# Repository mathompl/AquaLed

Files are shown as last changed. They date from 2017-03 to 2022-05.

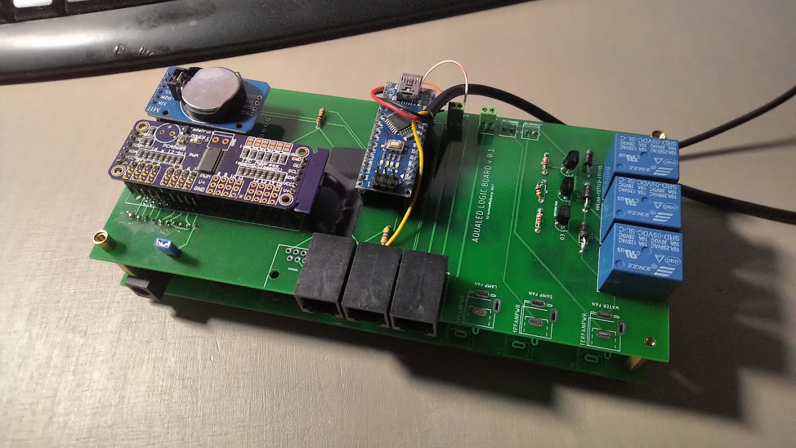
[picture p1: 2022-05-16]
pcb/IMG_20220514_2029458.jpg

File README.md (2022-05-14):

# AquaLed (en)

Arduino PWM LED lamp driver software with LCD support and temperature control for marine, reef or sweetwater aquariums.

Features:
- 8 channel PWM control of LED modules (drivers), with I2C module up to 512 (up to 8 channels on LCD)
- programmable light hours with sunsets and sunrises
- night light support
- 3 digital thermometers with asynchronous temperature read, for: water, lamp and addictional lamp or sump, controlling 3 separate  relays (cooling fans)
- customizable dimming, linear or logarithmic algorith
- bluetooth compatibility with AQma Led Control by Maqu http://magu.pl/aqma-led-control
- full configuration and status using Nextion 2.8" LCD with touch support, including: operational hours, sunset & sunrise hours, thermometers, dimming times, schedule, night mode etc.
- override programs: off, night and user accessible from LCD
- date/time support with RTC module
- screen saver with water temperature and time
- test mode
- moonphases simulation for night light
- all settings stored in EEPROM
- works on Arduino Nano

Example Nextion project attached. I dont have copyright for graphics used, use only as an example.

**Nextion LCD Screenshots**
 
AquaLed
AquaLed
AquaLed
AquaLed
AquaLed
AquaLed
AquaLed
AquaLed
AquaLed
AquaLed

**REQUIREMENTS:**

**Hardware:**
- Arduino Nano or better
- RTC module 
- Bluetooth (optional)
- 3x DS18B20 digital thermometers
- 3x 5v relays modules
- PCA9685 PWM i2c module (optional)
- Nextion 2.8" LCD

**Libraries:**
- Arduino-Temperature-Control-Library (https://github.com/milesburton/Arduino-Temperature-Control-Library) 
- DS1307RTC (https://github.com/PaulStoffregen/DS1307RTC)
- DS18B20 (https://github.com/nettigo/DS18B20)
- OneWire (https://github.com/PaulStoffregen/OneWire)
- Time (https://github.com/PaulStoffregen/Time)
- Adafruit-PWM-Servo-Driver-Library (https://github.com/adafruit/Adafruit-PWM-Servo-Driver-Library)
- or https://github.com/NachtRaveVL/PCA9685-Arduino

**Software:**
- Nextion Editor (https://nextion.itead.cc/download.html)
- Arduino IDE or atom.io

**Configuration:**
Driver configuration is in file aqualed.h

####PINS SETUP:
Configuration on LCD.

####Modules (uncomment to disable). As for now bluetooth and nextion support does not fit into Arduino Nano/UNO etc. flash memory. Use arduino Mega or disable one module support.
```
// modules, uncomment to disable, comment to enable
#define NO_BLUETOOTH
//#define NO_NEXTION
//#define NO_TEMPERATURE
```
####Other
There are many other options for eg. timers resolution, most of them are pretty self-explanatory ;)

**Wiring:**

AquaLed wiring

# AquaLed (pl)

Sterownik lampy LED PWM na Arduino z obsługą termometrów, chłodzenia i wyświetlacza LCD Nextion dla akwariów słodko i słonowodnych.

Możliwości:
- obsługa 8 ściemnialnych kanałów PWM dla modułów LED (driverów), z modułem I2C do 512 kanałów (maksymalnie 8 na wyswietlaczu)
- programowanie godzin świetenia z symulacją wschodów i zachodów słońca
- światło nocne
- obsługa 3 cyfrowych termometrów sterujących pracą 3 przekaźników (np. wentylatorów), np. dla lampy, lampy w sumpie, wody w akwarium
- ściemnianie/rozjaśnianie
- kompatybilność z AQma Led Control by Maqu http://magu.pl/aqma-led-control w zakresie programowania przez Bluetooth
- pełna konfiguracja i status za pomocą wyświetlacza Nextion LCD (przykłady na 2,8"), sterowanie przez dotyk.
- możliwość chwilowego nadpisania działającego programu z wyświetlacza: wyłączenie/wymuszenie światła nocnego/program zdefiniowany
- obsługa godziny i daty
- wygaszacz ekranu z godziną i temperaturą wody
- tryb test
- symulacja faz księżyca
- wszystkie ustawienia zapamiętywane w pamięci EEPROM
- działa z Arduino Nano lub wyższym modelem

Przykładowy program na wyświetlacz załączony.

**Wygląd ekranów na wyświetlaczu **

AquaLed
AquaLed
AquaLed
AquaLed
AquaLed
AquaLed
AquaLed
AquaLed
AquaLed
AquaLed

**Wymagania:**

**Sprzęt:**
- Arduino Nano lub wyższy
- moduł czasu rzeczywistego RTC
- Bluetooth (opcjonalnie)
- 3x termometry cyfrowe DS18B20
- 3x moduły przekaźników 5v
- moduł PCA9685 PWM i2c  (optionalny)
- wyświetlacz Nextion 2.8" LCD lub większy

**Biblioteki:**
- Arduino-Temperature-Control-Library (https://github.com/milesburton/Arduino-Temperature-Control-Library)
- DS1307RTC (https://github.com/PaulStoffregen/DS1307RTC)
- DS18B20 (https://github.com/nettigo/DS18B20)
- OneWire (https://github.com/PaulStoffregen/OneWire)
- Time (https://github.com/PaulStoffregen/Time)
- Adafruit-PWM-Servo-Driver-Library (https://github.com/adafruit/Adafruit-PWM-Servo-Driver-Library)
- lub https://github.com/NachtRaveVL/PCA9685-Arduino

**Oprogramowanie:**
- Nextion Editor (https://nextion.itead.cc/download.html)
- Arduino IDE lub atom.io

**Konfiguracja:**
Konfiguracja w pliku aqualed.h i nextion.h

####Ustawienia pinów PWM:
Konfiguracja z poziomu wyświetlacza.

####Moduły (odkomentuj żeby wyłączyć). Uwaga! Obsługa bluetooth i nextio nie mieści się jednocześnie w pamięcy flash Arduino Nano/Uno itd. wchodzi tylko do Arduino Mega lub podobnego.
```
// modules, uncomment to disable, comment to enable
#define NO_BLUETOOTH
//#define NO_NEXTION
//#define NO_TEMPERATURE
```
####Inne
W pliku konfiguracyjnym można ustawić wiele opcji w tym czasy działania timerów, rozdzielczość załączania przekaźników itd. Większość ustawień wynika z samych nazw stałych :)

**Podłączenie:**

AquaLed wiring

**PCB Prototype boards:**
AquaLed Logic PCB
AquaLed DRIVERS PCB

Support:http://nano-reef.pl/topic/88904-a-qualed-sterownik-led-termometry-lcd-nextion/

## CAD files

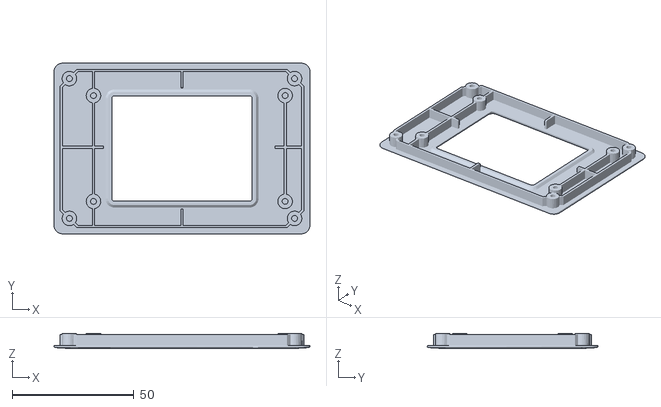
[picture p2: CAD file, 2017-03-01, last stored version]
devs/Aled.,6/Nextion/bezel/nextion_28_bezel.stl
105.0 x 70.0 x 6.15

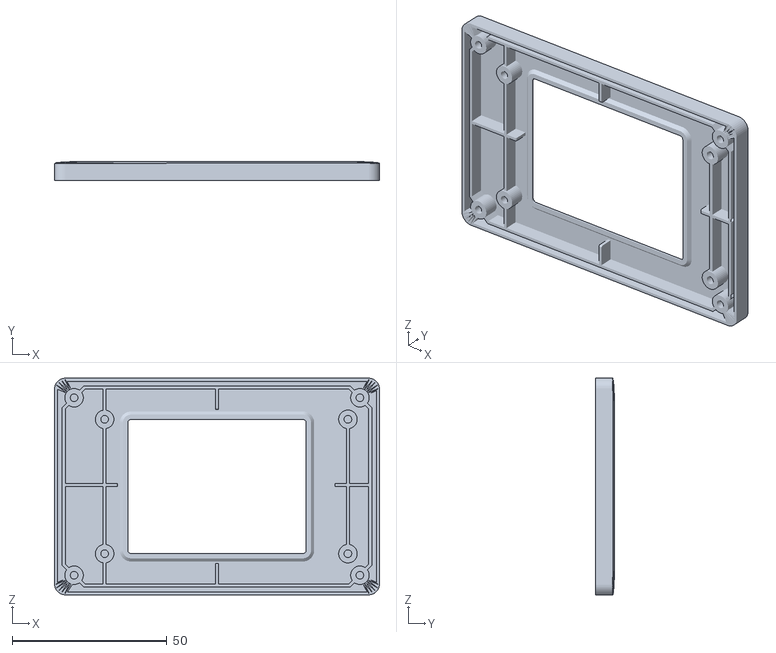
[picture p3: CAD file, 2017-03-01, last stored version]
devs/Aled.,6/Nextion/bezel/nextion-28.stl
105.0 x 6.15 x 70.0

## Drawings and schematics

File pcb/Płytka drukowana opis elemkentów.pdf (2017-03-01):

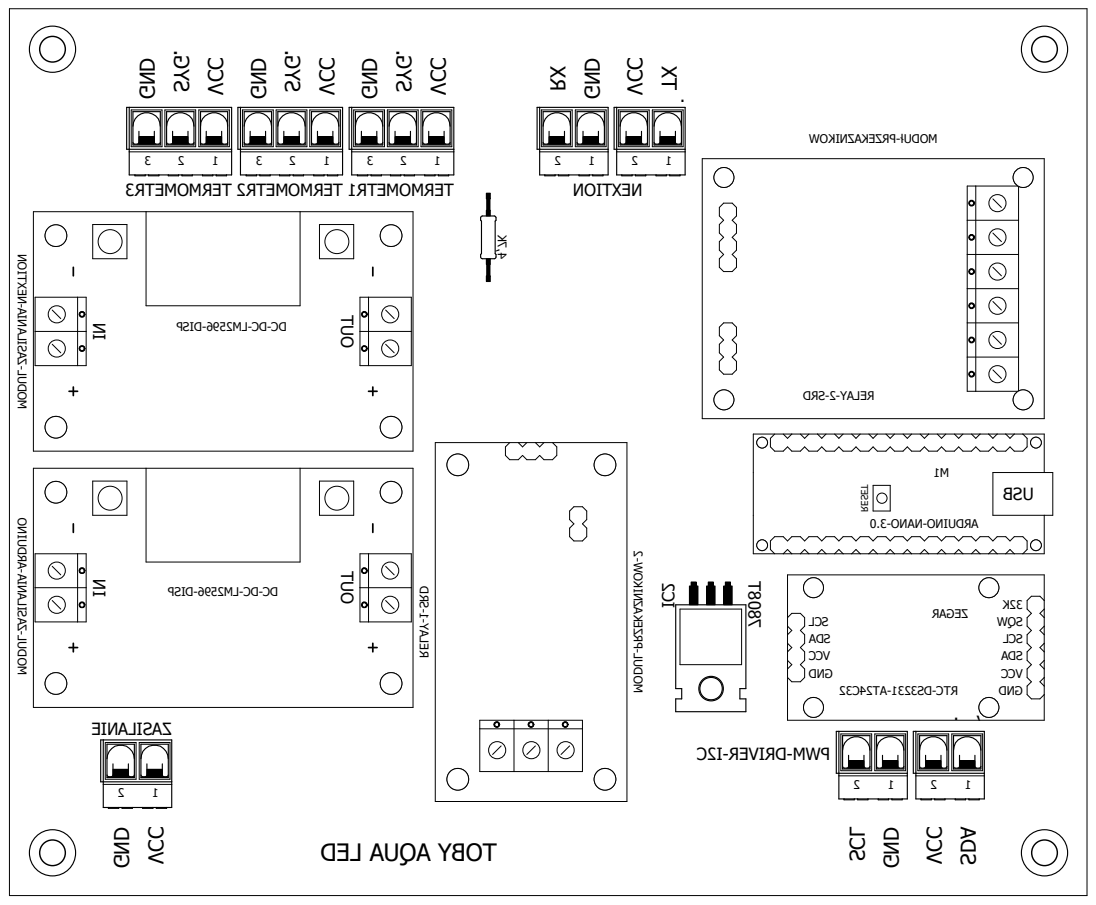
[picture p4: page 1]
MODUł-PRZEKAZNIKOW; TERMOMETR2 TERMOMETR1 TERMOMETR3; . NEXTION; ZASILANIE; PWM-DRIVER-I2C; 32K SQW SCL SDA; VCC GND; SCL SDA

1 2 1 2 1 2 GND VCC SCL GND VCC SDA GND SYG. VCC GND SYG. VCC GND SYG. VCC RX GND VCC TX

M1 MODUL-ZASILANIA-ARDUINO MODUL-ZASILANIA-NEXTION

USB RESET IN OUT IN OUT

DC-DC-LM2596-DISP RELAY-2-SRD

ARDUINO-NANO-3.0 DC-DC-LM2596-DISP

ZEGAR MODUL-PRZEKAZNIKOW-2

RTC-DS3231-AT24C32 RELAY-1-SRD

TOBY AQUA LED

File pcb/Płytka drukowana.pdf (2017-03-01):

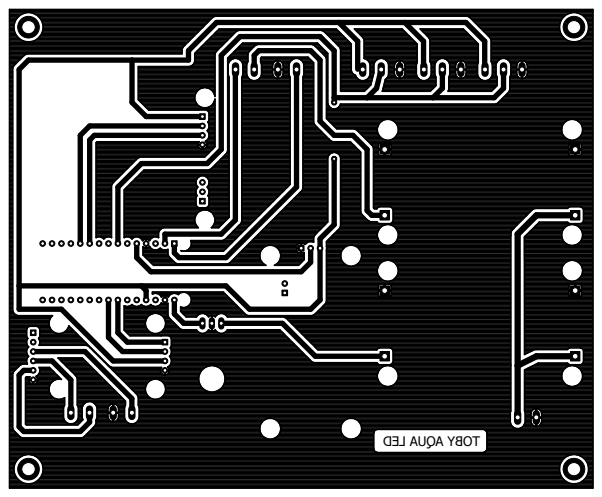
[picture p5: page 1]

TOBY AQUA LED

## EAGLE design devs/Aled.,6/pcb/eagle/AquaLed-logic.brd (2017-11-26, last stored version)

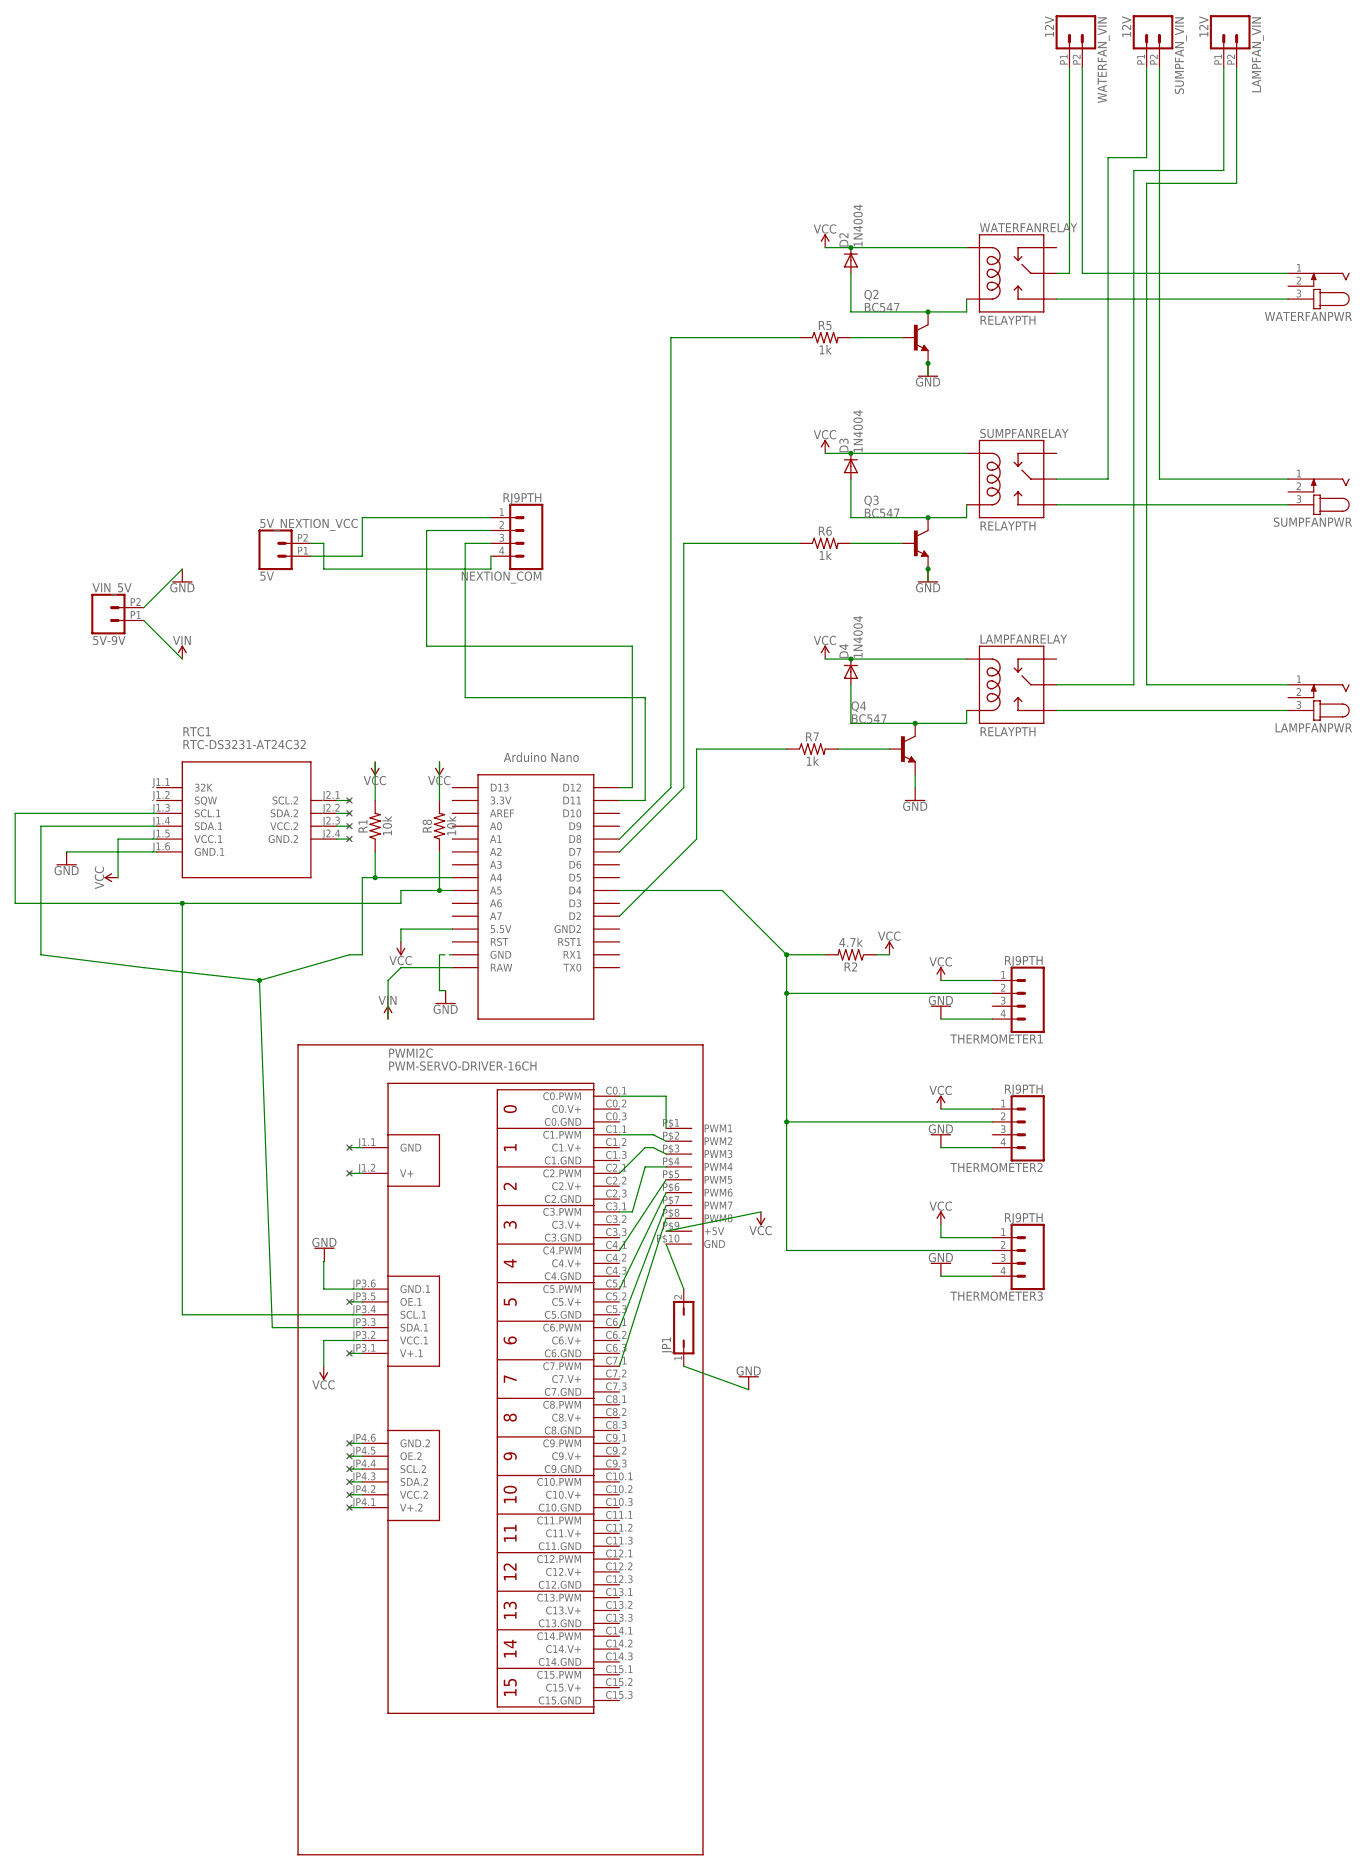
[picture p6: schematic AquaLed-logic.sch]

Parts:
5V_NEXTION_VCC: 5V; 1X02_2.54_SCREWTERM
D2, D3, D4: 1N4004; DO41-10
JP1: JP1Q; JP1
LAMPFANPWR: JACK-PLUG1; SPC4078
LAMPFANRELAY: RELAYPTH; SRD-05VDC-SL-C
LAMPFAN_VIN: 12V; 1X02_2.54_SCREWTERM
NEXTION_COM: RJ9PTH; RJ9
PWMI2C: PWM-SERVO-DRIVER-16CH
Q2, Q3, Q4: BC547; TO92
R1, R8: 10k; AXIAL-0.3
R2: 4.7k; AXIAL-0.3
R5, R6, R7: 1k; AXIAL-0.3
RTC1: RTC-DS3231-AT24C32
SUMPFANPWR: JACK-PLUG1; SPC4078
SUMPFANRELAY: RELAYPTH; SRD-05VDC-SL-C
SUMPFAN_VIN: 12V; 1X02_2.54_SCREWTERM
THERMOMETER1, THERMOMETER2, THERMOMETER3: RJ9PTH; RJ9
U$1: NANO
U$29: PCB
VIN_5V: 5V-9V; 1X02_2.54_SCREWTERM
WATERFANPWR: JACK-PLUG1; SPC4078
WATERFANRELAY: RELAYPTH; SRD-05VDC-SL-C
WATERFAN_VIN: 12V; 1X02_2.54_SCREWTERM

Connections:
GND: JP1.1, PWMI2C.JP3.6 (GND.1), Q2.1 (E), Q3.1 (E), Q4.1 (E), RTC1.J1.6 (GND.1), THERMOMETER1.4, THERMOMETER2.4, THERMOMETER3.4, U$1.GND, VIN_5V.P2 (2)
unnamed: R2.P$2 (2), THERMOMETER1.2, THERMOMETER2.2, THERMOMETER3.2, U$1.D4
unnamed: PWMI2C.JP3.3 (SDA.1), R1.P$1 (1), RTC1.J1.4 (SDA.1), U$1.A4
unnamed: R5.P$1 (1), U$1.D8
unnamed: R6.P$1 (1), U$1.D7
unnamed: LAMPFANPWR.3, LAMPFANRELAY.SWOPEN
unnamed: SUMPFANPWR.3, SUMPFANRELAY.SWOPEN
unnamed: LAMPFANRELAY.SWCOMMON, LAMPFAN_VIN.P1 (1)
unnamed: R7.P$1 (1), U$1.D2
unnamed: D2.A, Q2.3 (C), WATERFANRELAY.COIL0
unnamed: Q2.2 (B), R5.P$2 (2)
unnamed: SUMPFANPWR.1, SUMPFAN_VIN.P2 (2)
unnamed: D3.A, Q3.3 (C), SUMPFANRELAY.COIL0
unnamed: Q3.2 (B), R6.P$2 (2)
unnamed: LAMPFANPWR.1, LAMPFAN_VIN.P2 (2)
unnamed: D4.A, LAMPFANRELAY.COIL0, Q4.3 (C)
unnamed: Q4.2 (B), R7.P$2 (2)
unnamed: SUMPFANRELAY.SWCOMMON, SUMPFAN_VIN.P1 (1)
unnamed: WATERFANRELAY.SWCOMMON, WATERFAN_VIN.P1 (1)
unnamed: WATERFANPWR.1, WATERFAN_VIN.P2 (2)
unnamed: WATERFANPWR.3, WATERFANRELAY.SWOPEN
unnamed: 5V_NEXTION_VCC.P1 (1), NEXTION_COM.1
unnamed: 5V_NEXTION_VCC.P2 (2), NEXTION_COM.4
unnamed: NEXTION_COM.3, U$1.D11
unnamed: NEXTION_COM.2, U$1.D12
unnamed: PWMI2C.JP3.4 (SCL.1), R8.P$1 (1), RTC1.J1.3 (SCL.1), U$1.A5
unnamed: PWMI2C.C0.1 (C0.PWM), U$29.P$1 (PWM1)
unnamed: PWMI2C.C1.1 (C1.PWM), U$29.P$2 (PWM2)
unnamed: PWMI2C.C2.1 (C2.PWM), U$29.P$3 (PWM3)
unnamed: PWMI2C.C3.1 (C3.PWM), U$29.P$4 (PWM4)
unnamed: PWMI2C.C4.1 (C4.PWM), U$29.P$5 (PWM5)
unnamed: PWMI2C.C5.1 (C5.PWM), U$29.P$6 (PWM6)
unnamed: PWMI2C.C6.1 (C6.PWM), U$29.P$7 (PWM7)
unnamed: PWMI2C.C7.1 (C7.PWM), U$29.P$8 (PWM8)
unnamed: JP1.2, U$29.P$10 (GND)
VCC: D2.C, D3.C, D4.C, LAMPFANRELAY.COIL1, PWMI2C.JP3.2 (VCC.1), R1.P$2 (2), R2.P$1 (1), R8.P$2 (2), RTC1.J1.5 (VCC.1), SUMPFANRELAY.COIL1, THERMOMETER1.1, THERMOMETER2.1, THERMOMETER3.1, U$1.5V (5.5V), U$29.P$9 (+5V), WATERFANRELAY.COIL1
VIN: U$1.RAW, VIN_5V.P1 (1)

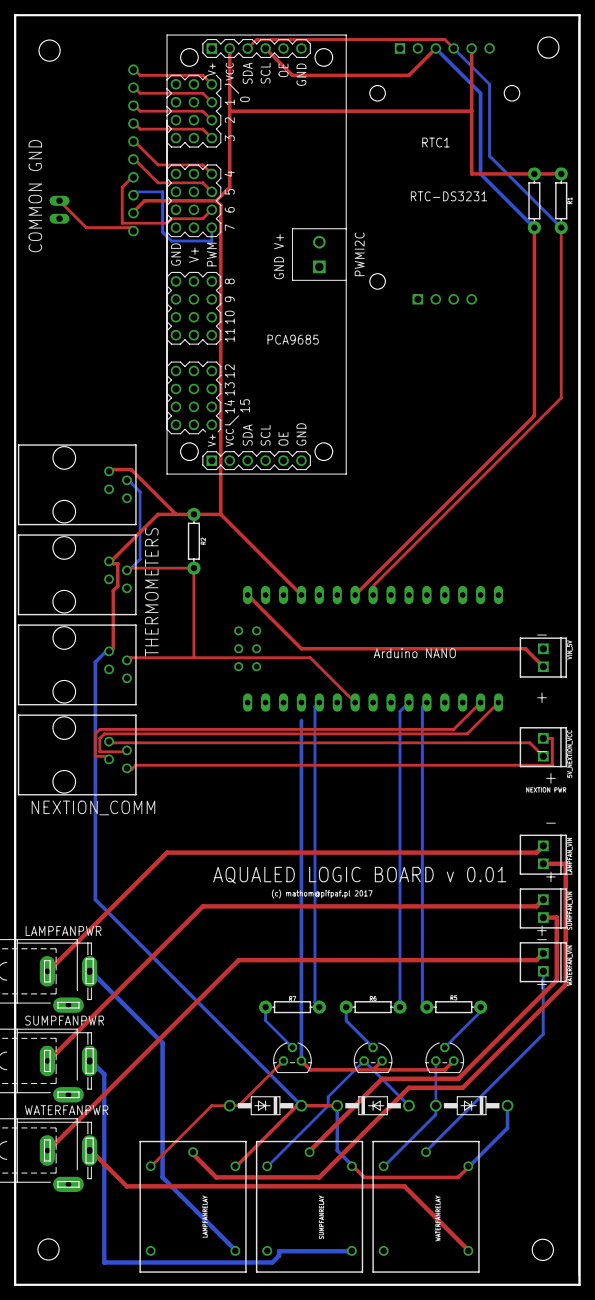
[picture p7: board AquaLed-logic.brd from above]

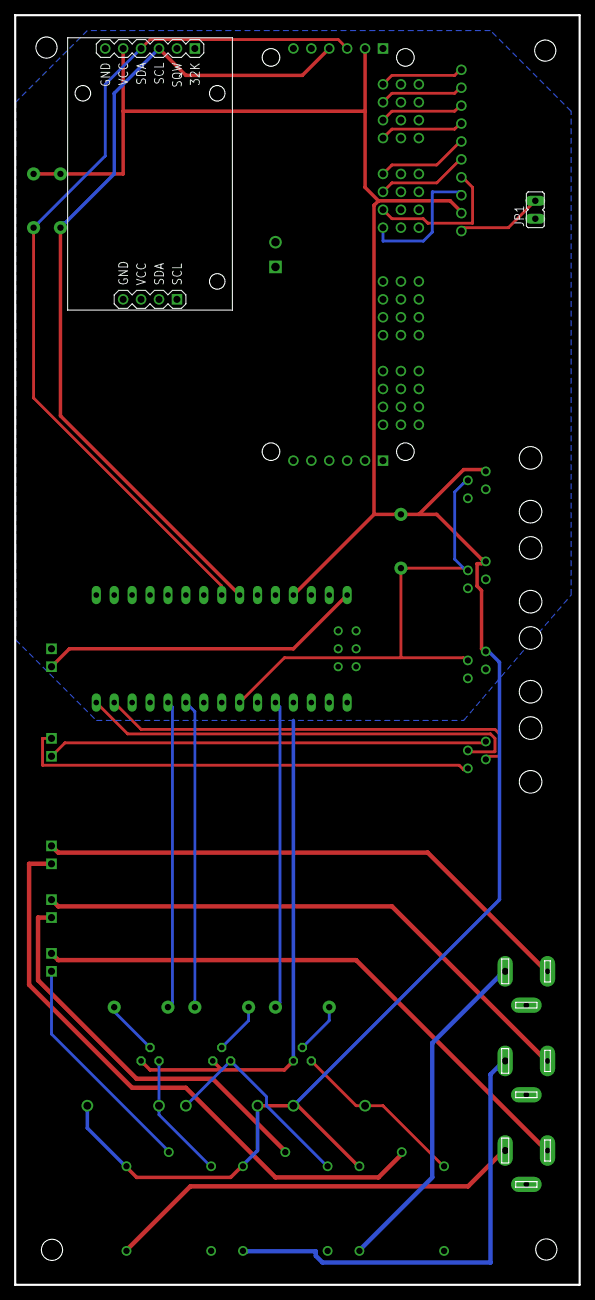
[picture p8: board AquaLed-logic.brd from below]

Board: 2 copper layers, 80.0 x 180.0 mm, 32 parts (2 on the bottom side), 37 nets.

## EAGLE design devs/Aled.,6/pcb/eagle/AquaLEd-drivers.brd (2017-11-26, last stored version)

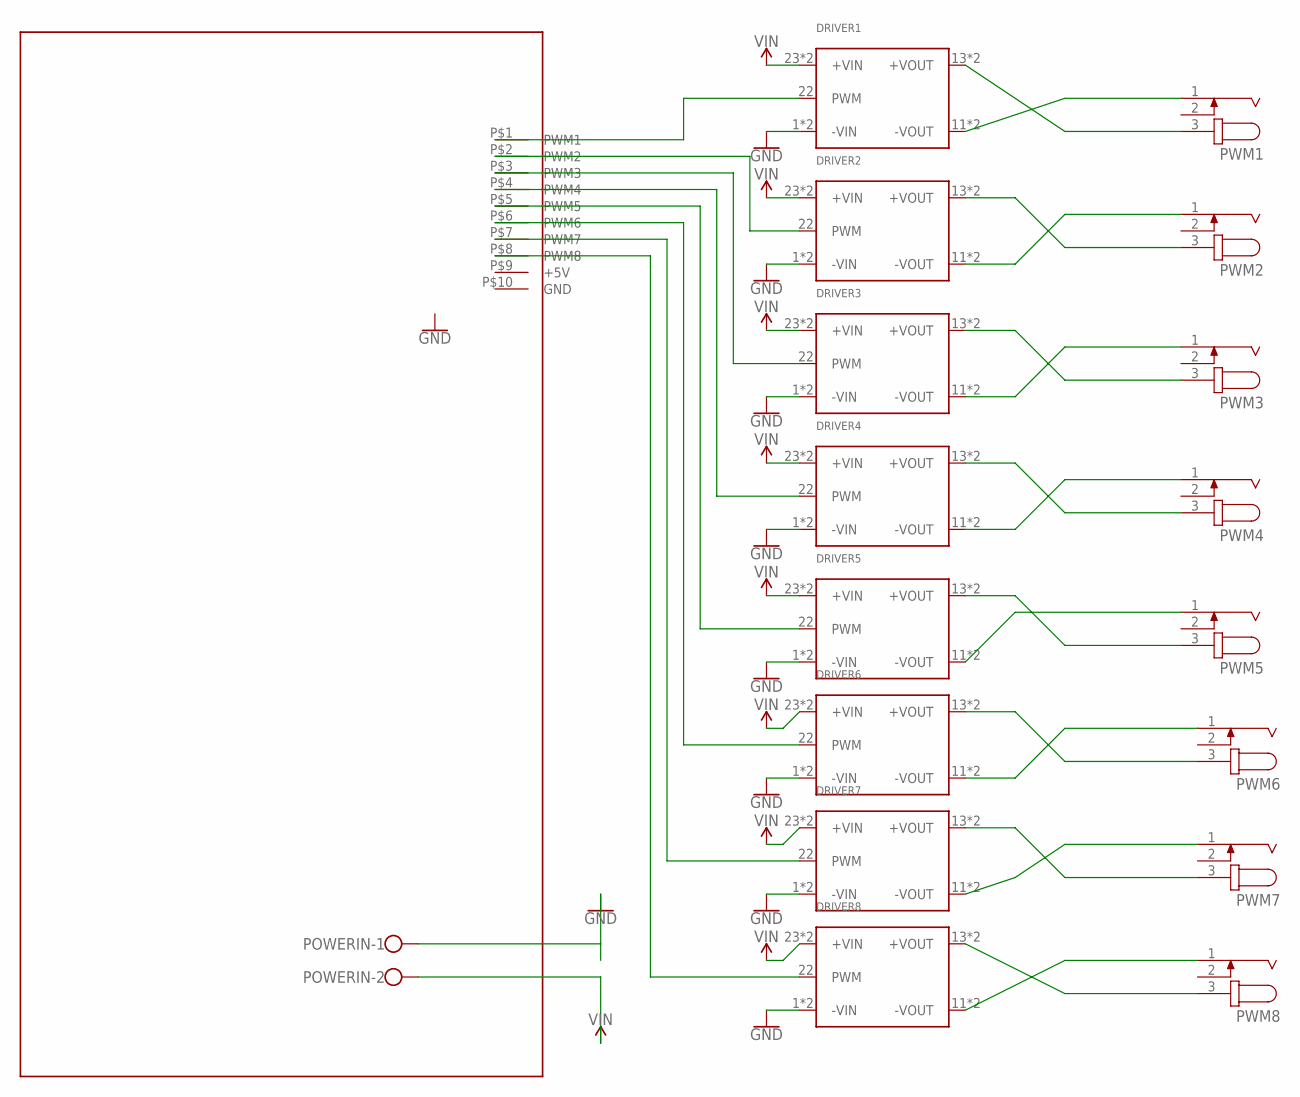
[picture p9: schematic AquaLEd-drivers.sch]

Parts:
DRIVER1, DRIVER2, DRIVER3, DRIVER4, DRIVER5, DRIVER6, DRIVER7, DRIVER8: LDD-H
POWERIN: W237-102
PWM1, PWM2, PWM3, PWM4, PWM5, PWM6, PWM7, PWM8: JACK-PLUG1; SPC4078
U$29: PCB

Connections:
+5V: U$29.P$9 (+5V)
GND: DRIVER1.1 (-VIN), DRIVER1.2 (-VIN), DRIVER2.1 (-VIN), DRIVER2.2 (-VIN), DRIVER3.1 (-VIN), DRIVER3.2 (-VIN), DRIVER4.1 (-VIN), DRIVER4.2 (-VIN), DRIVER5.1 (-VIN), DRIVER5.2 (-VIN), DRIVER6.1 (-VIN), DRIVER6.2 (-VIN), DRIVER7.1 (-VIN), DRIVER7.2 (-VIN), DRIVER8.1 (-VIN), DRIVER8.2 (-VIN), POWERIN.1, U$29.P$10 (GND)
unnamed: DRIVER1.22 (PWM), U$29.P$1 (PWM1)
unnamed: DRIVER8.11 (-VOUT), DRIVER8.12 (-VOUT), PWM8.1
unnamed: DRIVER8.13 (+VOUT), DRIVER8.14 (+VOUT), PWM8.3
unnamed: DRIVER7.11 (-VOUT), DRIVER7.12 (-VOUT), PWM7.1
unnamed: DRIVER7.13 (+VOUT), DRIVER7.14 (+VOUT), PWM7.3
unnamed: DRIVER6.11 (-VOUT), DRIVER6.12 (-VOUT), PWM6.1
unnamed: DRIVER6.13 (+VOUT), DRIVER6.14 (+VOUT), PWM6.3
unnamed: DRIVER5.11 (-VOUT), DRIVER5.12 (-VOUT), PWM5.1
unnamed: DRIVER5.13 (+VOUT), DRIVER5.14 (+VOUT), PWM5.3
unnamed: DRIVER4.11 (-VOUT), DRIVER4.12 (-VOUT), PWM4.1
unnamed: DRIVER4.13 (+VOUT), DRIVER4.14 (+VOUT), PWM4.3
unnamed: DRIVER3.11 (-VOUT), DRIVER3.12 (-VOUT), PWM3.1
unnamed: DRIVER3.13 (+VOUT), DRIVER3.14 (+VOUT), PWM3.3
unnamed: DRIVER2.11 (-VOUT), DRIVER2.12 (-VOUT), PWM2.1
unnamed: DRIVER2.13 (+VOUT), DRIVER2.14 (+VOUT), PWM2.3
unnamed: DRIVER1.11 (-VOUT), DRIVER1.12 (-VOUT), PWM1.1
unnamed: DRIVER1.13 (+VOUT), DRIVER1.14 (+VOUT), PWM1.3
unnamed: DRIVER2.22 (PWM), U$29.P$2 (PWM2)
unnamed: DRIVER3.22 (PWM), U$29.P$3 (PWM3)
unnamed: DRIVER4.22 (PWM), U$29.P$4 (PWM4)
unnamed: DRIVER5.22 (PWM), U$29.P$5 (PWM5)
unnamed: DRIVER6.22 (PWM), U$29.P$6 (PWM6)
unnamed: DRIVER7.22 (PWM), U$29.P$7 (PWM7)
unnamed: DRIVER8.22 (PWM), U$29.P$8 (PWM8)
VIN: DRIVER1.23 (+VIN), DRIVER1.24 (+VIN), DRIVER2.23 (+VIN), DRIVER2.24 (+VIN), DRIVER3.23 (+VIN), DRIVER3.24 (+VIN), DRIVER4.23 (+VIN), DRIVER4.24 (+VIN), DRIVER5.23 (+VIN), DRIVER5.24 (+VIN), DRIVER6.23 (+VIN), DRIVER6.24 (+VIN), DRIVER7.23 (+VIN), DRIVER7.24 (+VIN), DRIVER8.23 (+VIN), DRIVER8.24 (+VIN), POWERIN.2

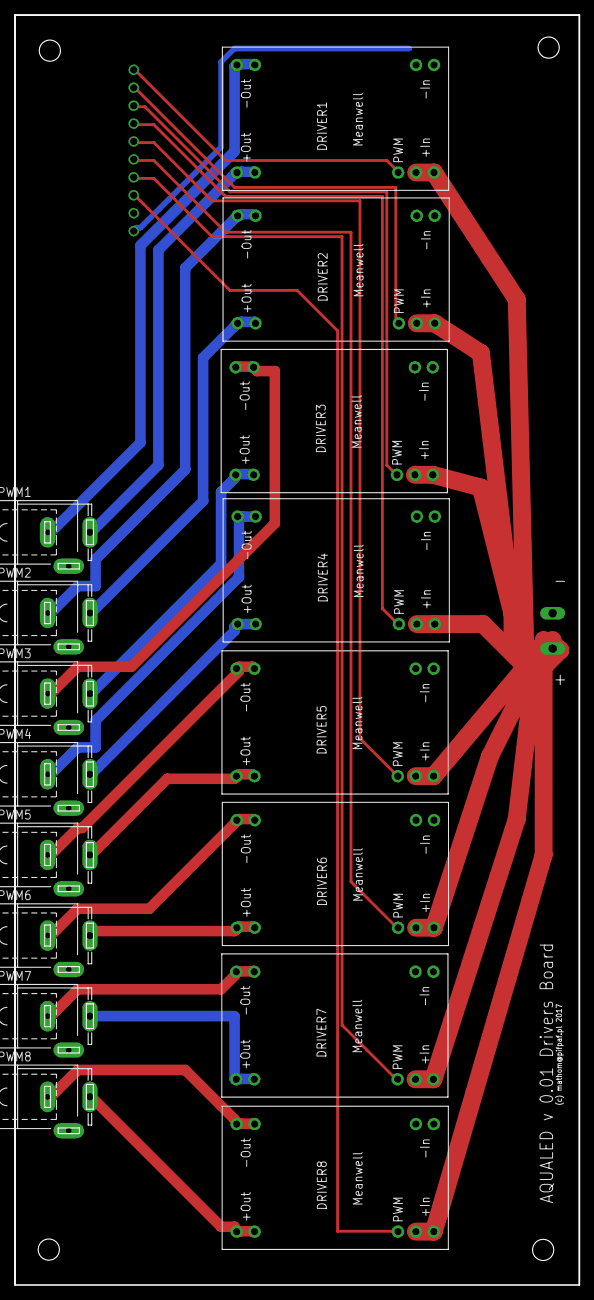
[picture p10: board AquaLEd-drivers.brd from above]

Board: 2 copper layers, 80.0 x 180.0 mm, 18 parts (1 on the bottom side), 26 nets.

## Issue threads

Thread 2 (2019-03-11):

Compile problem

Allhappy, 2019-03-11:
Hello, tanks for sharing your project!
I´m testing it right now, and I´m loving it...
I have a problem when I uncomment the line #define NO_BLUETOOTH for activating the bluetooth module
The arduino IDE return me a few errors ( I´m not a programming expert :P )

My current setup is:

- lights with 3 channels controlled by pwm
- 3 temperature sensors DS18B20 (Water, Leds, pwm drivers)
- 8 relay board for 230V switch, 4 currently in use (Heater, Filter, CO2, Skimmer)

I´m electronic technician , and my programming skills are limited for now, a help is much appreciated !

Thanks in advance!

Allhappy, 2019-03-14:
And I forgot to say, I´m using arduino Mega.

Allhappy, 2019-03-18:
I have another problem, the temperature control is not working, when the maximum temperature is reached, the relay is not activated nor does the "fan" icon appear, but if you reset it at that time, the relay is activated and the icon lights up.

mathompl, 2019-10-17:
Bluetooth support is not tested, it should work and is compatible with MAGU software, but i didnt test it because the display itself was sufficient for me.

I've uploaded current sources and nextion files today, please check if the temperature works. I think there were some problems with compatibility of nextion code and arduino sources.

The relay on reset might be activated by arduino boot. Please check if the pins are corretly set in config.h. Also please check if you have the correct libraries and if the wiring of the relays is correct.

Relays pins are:
// relay's pins
#define LED_FANS_PIN 2   // lamp fans relay pin
#define WATER_FANS_PIN 8 // water  fans relay pin
#define SUMP_FANS_PIN 7  // sump fans relay pin

Those are for arduino nano, please check if mega has the same pin mappings.

On newest version you can click on the screen next to the temperature (very small area, use pencil) to switch corresponding relay to test it. Also the relays are switched in 5 minutes intervals, so it wont switch immediately after the temperature has been reached.

Allhappy, 2020-03-09:
Hi, thanks for your answer! I will test it soon!
thanks in advance.

Closed 2022-05-04.

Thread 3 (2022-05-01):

[ask] Issue on RTC library

isnuryusuf, 2022-05-01:
Hi, nice work!!

i have problem on RTC lib version
look like i cannot find rtcSetup, getMoonPhase , readTime, adjustDST  and others function
have try to install low version to latest version from https://github.com/adafruit/RTClib with no luck

iam using Arduino Mega Atmega2560  on Arduino IDE

Thanks before

`
C:\Users\yusuf\Arduino\Project\AquaLed-master\Aqualed\Aqualed.ino: In function 'void setup()':
Aqualed:43:9: error: 'rtcSetup' was not declared in this scope
         rtcSetup ();
         ^~~~~~~~
C:\Users\yusuf\Arduino\Project\AquaLed-master\Aqualed\Aqualed.ino:43:9: note: suggested alternative: 'setup'
         rtcSetup ();
         ^~~~~~~~
         setup
Aqualed:45:9: error: 'getMoonPhase' was not declared in this scope
         getMoonPhase ();
         ^~~~~~~~~~~~
C:\Users\yusuf\Arduino\Project\AquaLed-master\Aqualed\Aqualed.ino:45:9: note: suggested alternative: 'moonPhase'
         getMoonPhase ();
         ^~~~~~~~~~~~
         moonPhase
C:\Users\yusuf\Arduino\Project\AquaLed-master\Aqualed\Aqualed.ino: In function 'void loop()':
Aqualed:66:9: error: 'readTime' was not declared in this scope
         readTime ();
         ^~~~~~~~
C:\Users\yusuf\Arduino\Project\AquaLed-master\Aqualed\Aqualed.ino:66:9: note: suggested alternative: 'currTime'
         readTime ();
         ^~~~~~~~
         currTime
C:\Users\yusuf\Arduino\Project\AquaLed-master\Aqualed\Nextion.ino: In function 'boolean handleTestSlider(int, byte)':
Nextion:190:38: error: 'mapRound' was not declared in this scope
         pwmRuntime[i].valueCurrent = mapRound ((long)t, 0, 100, 0, PWM_I2C_MAX);
                                      ^~~~~~~~
C:\Users\yusuf\Arduino\Project\AquaLed-master\Aqualed\Nextion.ino:190:38: note: suggested alternative: 'round'
         pwmRuntime[i].valueCurrent = mapRound ((long)t, 0, 100, 0, PWM_I2C_MAX);
                                      ^~~~~~~~
                                      round
C:\Users\yusuf\Arduino\Project\AquaLed-master\Aqualed\Nextion.ino: In function 'void handlePWMPage(byte)':
Nextion:279:48: error: 'mapRound' was not declared in this scope
                 pwmSettings[i - 1].valueProg = mapRound (pwmSettings[i - 1].valueProg, 0, 100, 0, PWM_I2C_MAX);
                                                ^~~~~~~~
C:\Users\yusuf\Arduino\Project\AquaLed-master\Aqualed\Nextion.ino:279:48: note: suggested alternative: 'round'
                 pwmSettings[i - 1].valueProg = mapRound (pwmSettings[i - 1].valueProg, 0, 100, 0, PWM_I2C_MAX);
                                                ^~~~~~~~
                                                round
C:\Users\yusuf\Arduino\Project\AquaLed-master\Aqualed\Nextion.ino: In function 'void handleSetTimePage(byte)':
Nextion:351:17: error: 'readTime' was not declared in this scope
                 readTime ();
                 ^~~~~~~~
C:\Users\yusuf\Arduino\Project\AquaLed-master\Aqualed\Nextion.ino:351:17: note: suggested alternative: 'currTime'
                 readTime ();
                 ^~~~~~~~
                 currTime
Nextion:352:17: error: 'adjustDST' was not declared in this scope
                 adjustDST ();
                 ^~~~~~~~~
C:\Users\yusuf\Arduino\Project\AquaLed-master\Aqualed\Nextion.ino: In function 'void handleConfigPage(byte)':
Nextion:503:21: error: 'discoverOneWireDevices' was not declared in this scope
                 s = discoverOneWireDevices ();
                     ^~~~~~~~~~~~~~~~~~~~~~
Nextion:522:26: error: 'listContains' was not declared in this scope
                 idxLed = listContains (settings.sensors[LED_TEMPERATURE_FAN]);
                          ^~~~~~~~~~~~
C:\Users\yusuf\Arduino\Project\AquaLed-master\Aqualed\Nextion.ino:522:26: note: suggested alternative: 'isControl'
                 idxLed = listContains (settings.sensors[LED_TEMPERATURE_FAN]);
                          ^~~~~~~~~~~~
                          isControl
Nextion:540:50: error: 'mapRound' was not declared in this scope
                         setValue (NX_FIELD_N0+i, mapRound (pwmRuntime[i].valueCurrent, 0, PWM_I2C_MAX, 0, 100));
                                                  ^~~~~~~~
C:\Users\yusuf\Arduino\Project\AquaLed-master\Aqualed\Nextion.ino:540:50: note: suggested alternative: 'round'
                         setValue (NX_FIELD_N0+i, mapRound (pwmRuntime[i].valueCurrent, 0, PWM_I2C_MAX, 0, 100));
                                                  ^~~~~~~~
                                                  round
C:\Users\yusuf\Arduino\Project\AquaLed-master\Aqualed\Nextion.ino: In function 'void handlePWMListPage(byte)':
Nextion:615:31: error: 'mapRound' was not declared in this scope
                 tmax = (byte) mapRound (pwmSettings[cid - 1].valueDay, 0, PWM_I2C_MAX, 0, 100);
                               ^~~~~~~~
C:\Users\yusuf\Arduino\Project\AquaLed-master\Aqualed\Nextion.ino:615:31: note: suggested alternative: 'round'
                 tmax = (byte) mapRound (pwmSettings[cid - 1].valueDay, 0, PWM_I2C_MAX, 0, 100);
                               ^~~~~~~~
                               round
C:\Users\yusuf\Arduino\Project\AquaLed-master\Aqualed\Nextion.ino: In function 'double getPercent(byte)':
Nextion:867:16: error: 'mapDouble' was not declared in this scope
         return mapDouble((double)pwmRuntime[i].valueCurrent, 0.0, (double)PWM_I2C_MAX, 0.0, 100.0);
                ^~~~~~~~~
C:\Users\yusuf\Arduino\Project\AquaLed-master\Aqualed\Nextion.ino:867:16: note: suggested alternative: 'double'
         return mapDouble((double)pwmRuntime[i].valueCurrent, 0.0, (double)PWM_I2C_MAX, 0.0, 100.0);
                ^~~~~~~~~
                double
C:\Users\yusuf\Arduino\Project\AquaLed-master\Aqualed\PWM.ino: In function 'void setupPWMPins()':
PWM:24:35: error: no matching function for call to 'init(int)'
         pwmController.init(B000000); // Address pins A5-A0 set to B000000
                                   ^
In file included from C:\Users\yusuf\Arduino\Project\AquaLed-master\Aqualed\PWM.ino:9:0:
C:\Users\yusuf\Documents\Arduino\libraries\PCA9685-Arduino-1.2.15\src/PCA9685.h:204:10: note: candidate: void PCA9685::init(PCA9685_OutputDriverMode, PCA9685_OutputEnabledMode, PCA9685_OutputDisabledMode, PCA9685_ChannelUpdateMode, PCA9685_PhaseBalancer) <near match>
     void init(PCA9685_OutputDriverMode driverMode = PCA9685_OutputDriverMode_TotemPole,
          ^~~~
C:\Users\yusuf\Documents\Arduino\libraries\PCA9685-Arduino-1.2.15\src/PCA9685.h:204:10: note:   conversion of argument 1 would be ill-formed:
C:\Users\yusuf\Documents\Arduino\libraries\PCA9685-Arduino-1.2.15\src/PCA9685.h:211:10: note: candidate: void PCA9685::init(PCA9685_PhaseBalancer, PCA9685_OutputDriverMode, PCA9685_OutputEnabledMode, PCA9685_OutputDisabledMode, PCA9685_ChannelUpdateMode) <near match>
     void init(PCA9685_PhaseBalancer phaseBalancer,
          ^~~~
C:\Users\yusuf\Documents\Arduino\libraries\PCA9685-Arduino-1.2.15\src/PCA9685.h:211:10: note:   conversion of argument 1 would be ill-formed:
PWM:30:9: error: 'getCurrentTime' was not declared in this scope
         getCurrentTime ();
         ^~~~~~~~~~~~~~
C:\Users\yusuf\Arduino\Project\AquaLed-master\Aqualed\PWM.ino:30:9: note: suggested alternative: 'getPercent'
         getCurrentTime ();
         ^~~~~~~~~~~~~~
         getPercent
C:\Users\yusuf\Arduino\Project\AquaLed-master\Aqualed\PWM.ino: In function 'void pwm(byte)':
PWM:262:31: error: 'mapRound' was not declared in this scope
                         val = mapRound(val,  PWM_I2C_MAX, PWM_I2C_MIN,  0, 255);
                               ^~~~~~~~
C:\Users\yusuf\Arduino\Project\AquaLed-master\Aqualed\PWM.ino:262:31: note: suggested alternative: 'round'
                         val = mapRound(val,  PWM_I2C_MAX, PWM_I2C_MIN,  0, 255);
                               ^~~~~~~~
                               round
PWM:264:31: error: 'mapRound' was not declared in this scope
                         val = mapRound(val, PWM_I2C_MIN, PWM_I2C_MAX,  0, 255);
                               ^~~~~~~~
C:\Users\yusuf\Arduino\Project\AquaLed-master\Aqualed\PWM.ino:264:31: note: suggested alternative: 'round'
                         val = mapRound(val, PWM_I2C_MIN, PWM_I2C_MAX,  0, 255);
                               ^~~~~~~~
                               round
PWM:279:39: error: 'mapRound' was not declared in this scope
                                 val = mapRound(val, PWM_I2C_MAX, 0.0, PWM_I2C_MIN, PWM_I2C_MAX);
                                       ^~~~~~~~
C:\Users\yusuf\Arduino\Project\AquaLed-master\Aqualed\PWM.ino:279:39: note: suggested alternative: 'round'
                                 val = mapRound(val, PWM_I2C_MAX, 0.0, PWM_I2C_MIN, PWM_I2C_MAX);
                                       ^~~~~~~~
                                       round
C:\Users\yusuf\Arduino\Project\AquaLed-master\Aqualed\PWM.ino: In function 'void pwm()':
PWM:336:17: error: 'getCurrentTime' was not declared in this scope
                 getCurrentTime ();
                 ^~~~~~~~~~~~~~
C:\Users\yusuf\Arduino\Project\AquaLed-master\Aqualed\PWM.ino:336:17: note: suggested alternative: 'getPercent'
                 getCurrentTime ();
                 ^~~~~~~~~~~~~~
                 getPercent
C:\Users\yusuf\Arduino\Project\AquaLed-master\Aqualed\Temperature.ino: In function 'void fansControl()':
Temperature:56:25: error: 'fansSwitch' was not declared in this scope
                         fansSwitch (i, settings.maxTemperatures[i]);
                         ^~~~~~~~~~
C:\Users\yusuf\Arduino\Project\AquaLed-master\Aqualed\Temperature.ino:56:25: note: suggested alternative: 'relaySwitch'
                         fansSwitch (i, settings.maxTemperatures[i]);
                         ^~~~~~~~~~
                         relaySwitch
In file included from C:\Users\yusuf\Arduino\Project\AquaLed-master\Aqualed\Aqualed.ino:3:0:
C:\Users\yusuf\Arduino\Project\AquaLed-master\Aqualed\Temperature.ino: At global scope:
C:\Users\yusuf\Documents\Arduino\libraries\DS18B20-master/DS18B20.h:9:20: error: expected initializer before '-' token
 #define TEMP_ERROR -273.15f
                    ^
C:\Users\yusuf\Arduino\Project\AquaLed-master\Aqualed\Temperature.ino:72:1: note: in expansion of macro 'TEMP_ERROR'
 TEMP_ERROR = 40
 ^~~~~~~~~~
C:\Users\yusuf\Arduino\Project\AquaLed-master\Aqualed\Time.ino: In function 'void readTime()':
Time:30:9: error: 'adjustDST' was not declared in this scope
         adjustDST ();
         ^~~~~~~~~
C:\Users\yusuf\Arduino\Project\AquaLed-master\Aqualed\Time.ino: In function 'void adjustDST()':
Time:47:17: error: 'getMoonPhase' was not declared in this scope
                 getMoonPhase ();
                 ^~~~~~~~~~~~
C:\Users\yusuf\Arduino\Project\AquaLed-master\Aqualed\Time.ino:47:17: note: suggested alternative: 'moonPhase'
                 getMoonPhase ();
                 ^~~~~~~~~~~~
                 moonPhase
exit status 1
'rtcSetup' was not declared in this scope
`

mathompl, 2022-05-02:
did you try to compile in platform.io ?

it looks as it doesnt include some files like utils.ino etc.

maybe there is a problem with DS18B20 library:
```
C:\Users\yusuf\Documents\Arduino\libraries\DS18B20-master/DS18B20.h:9:20: error: expected initializer before '-' token
 #define TEMP_ERROR -273.15f
```

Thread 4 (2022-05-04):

Random arduino crashes

mathompl, 2022-05-04:
I'm experiencing random arduino crashes/lockups after ca. 4 years of lamp operation.

Most of the wirings, arduino, pwm controller and rtc modules were replaced. PCB looks mostly good with some oxidation.

Causes - I think related to possible electrical noise caused by hardware age, tough working environment (salt water, moisture) and maybe to aging led drivers:
1. In function nxTouch() there wasn't check on array lenght when writing. In some situations (noise on serial line) this might result in writing out of array boundaries - fixed, lockups still occur.
2. There might be a problem with Wire library and potential endless loop in function endTransation (). This issue is well documented, the updated library has a new method setWireTimeout() for avoiding this.  Again - this may be the case with noise on i2c lines. Timeout added - in testing.
3. There might be a problem with OneWire - again electrical - testing on the way.
4. There is a slight possibility of damaged transistors controlling the relays, and current backflow to gpio - i have to get into that.

Arduino's watchdog doesn't reset the board.

I will publish patches after testing for a few days.

Closed 2022-05-07.

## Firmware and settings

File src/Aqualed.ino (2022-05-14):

#include <Arduino.h>
#include <Wire.h>
#include "Aqualed.h"

/*
    AQUALED Arduino PWM LED lamp driver software with LCD support and temperature control for marine, reef or sweetwater aquariums.

    Features:

    - 6 channel PWM control of LED modules (drivers), with I2C module up to 512 (up to 8 channels on LCD)
    - programmable light hours with sunsets and sunrises
    - night light support
    - 3 digital thermometers with asynchronous temperature read, for: water, lamp and addictional lamp or sump, controlling 3 separate relays (cooling fans)
    - customizable dimming, linear or logarithmic algorith
    - bluetooth compatibility with AQma Led Control by Maqu http://magu.pl/aqma-led-control
    - full configuration and status using Nextion 2.8" LCD with touch support, including: operational hours, sunset & sunrise hours, thermometers, dimming times, schedule, night mode etc.
    - override programs: off, night and user accessible from LCD
    - date/time support with RTC module
    - screen saver with water temperature and time
    - test mode
    - all settings stored in EEPROM

     (c) 2016 - 2017 Tomek Formanowski mathom@pifpaf.pl
     Open Source public domain

     Use at your own risk.

     for config see:
     @aqualed.h
     @nextion.h

     published on github:
     https://github.com/mathompl/AquaLed
 */

void setup() {
  #ifdef ENABLE_WATCHDOG
        wdt_disable();
  #endif

// first run - erase eeprom
        writeEEPROMDefaults ();

// read settings from eeprom
        eEpromRead();

// configure RTC
        rtcSetup ();

// first time read
        readTimes ();
        getMoonPhase ();

#ifndef NO_TEMPERATURE
        setupSensors ();
#endif

#ifndef NO_BLUETOOTH
        setupBluetooth ();
#endif

#ifndef NO_NEXTION
        nexInit();
#endif
        setupPWMPins ();

        Wire.setWireTimeout(3000, true);

#ifdef ENABLE_WATCHDOG
        wdt_enable(WDTO_2S);
#endif

}


void loop() {
        // time
        readTimes ();
        // pwm
        pwm ();
        // nextion routines
#ifndef NO_NEXTION
        // nextion touch istener
        nxTouch();
        // nextion display
        nxDisplay ();
#endif
        // temperature and fans control
#ifndef NO_TEMPERATURE
        fansControl ();
#endif
        // bluetooth routines
#ifndef NO_BLUETOOTH
        bluetoothServe ();
#endif

        // clear Wire timeout
        Wire.clearWireTimeoutFlag();

#ifdef ENABLE_WATCHDOG
        wdt_reset();
#endif

}

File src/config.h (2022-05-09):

#ifndef CONFIG_H
#define CONFIG_H
/*
   AQUALED user configuration file (c) T. Formanowski 2016-2017
   https://github.com/mathompl/AquaLed
 */

#include <Arduino.h>
#include <avr/pgmspace.h>


// modules, uncomment to disable, comment to enable
#define NO_BLUETOOTH
//#define NO_NEXTION
//#define NEXTION_SOFTWARE_SERIAL // warning, soft serial is unreliable, use
// hardware serial if possible
#define NO_DIMMING_TABLE
//#define USE_ADAFRUIT_LIBRARY
//#define NO_TEMPERATURE
//#define ENABLE_WATCHDOG

// PWM channels count
#define PWMS 8

// PWM channels displayed names
#define PWM_1_NAME "CoolWhite 1\0"
#define PWM_2_NAME "CoolWhite 2\0"
#define PWM_3_NAME "RoyalBlue 1\0"
#define PWM_4_NAME "RoyalBlue 2\0"
#define PWM_5_NAME "RoyalBlue 3\0"
#define PWM_6_NAME "Blue\0"
#define PWM_7_NAME "Actinic\0"
#define PWM_8_NAME "Sump\0"

#define WATER_TEMPERATURE_MIN 24 // for coloring water temperature

// i2c configuration
#define PWM_I2C_MIN 0.0    // lower value of i2c scale
#define PWM_I2C_MAX 4096.0 // uper value
#define PWM_I2C_FREQ 1000   // i2c frequency (hz)

// termometry
#define ONEWIRE_PIN 4 // ds18b20 thermometers pin

// if NEXTION_SOFTWARE_SERIAL defined, configure pins (use with different
// pins - not standard arduino hardware serial port)
// Warning! Softwareserial is unrealiable and adds a fair amout of overhead,
// data loss may occur
#define NEXTION_SOFTWARE_PIN_TX 12
#define NEXTION_SOFTWARE_PIN_RX 11

// relay's pins
#define LED_FANS_PIN 2   // lamp fans relay pin
#define WATER_FANS_PIN 8 // water  fans relay pin
#define SUMP_FANS_PIN 7  // sump fans relay pin

// resolutions
#define PWM_RESOLUTION 100 // ms main PWM loop resolution (ticks in ms)
#define PWM_RESOLUTION_R 1.0 / PWM_RESOLUTION
#define PWM_MIN_STEP 0.00001             // minimum pwm change step
#define PWM_ADJUST_STEP_TICKS 10         // counter to re-adjust pwm step value
#define NX_INFO_RESOLUTION 1000          // ms - nextion home page refresh time
#define TEMPERATURE_SAMPLE_INTERVAL 1000 // ms temperature reading resolution
#define TIME_ADJUST_INTERVAL 900000      // ms daylight saving mode check
#define RTC_CALL_INTERVAL 1000      // ms how often check RTC time

// rozdzielczosc przekaznikow (s)
#define FANS_INTERVAL 300000 // ms fans resolution

// lamp protection
// max lamp wattage, used for lamp shutdown (psu protection)
#define MAX_WATTS 250
#define LAMP_TEMPERATURE_MAX 70 // max lamp temperature, used for lamp shutdown

#endif

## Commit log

2016-10-28 wiring diagram
2016-10-30 fixed serious bug in sunsets (wrong data types)
    [Bluetooth.ino, EEPROM.ino, Nextion.ino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]
2016-11-02 i2c settings (pwm i2c module)
2016-11-03 i2c frequency in cofig
2016-11-08 fixed bug in setting Nextion baud rate
    [Aqualed.ino, Bluetooth.ino, Nextion.ino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]
2016-12-23 Build-in/i2c PWM default values switching configured by USE_I2C_PWM_MODULE compiler directive
2017-01-01 fixed serious bug preventing dimming time to be >30s (variable overflow)
    [PWM.ino]
2017-01-26 added: schedule menu current time startx and starty
2017-01-31 fixed serious bug with sunset & sunrise lenght
    [Aqualed.ino, PWM.ino, aqualed.h]
2017-02-03 Fixed numerous bugs: - when sunset ended before scheduled hour, nightmode was not kicking in - increased sunset/sunrise resolution, in certain situations sunset/sunrise time was shorter then schedule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
    New features:
    - after crash or forced mode lamp recovers to last state (usefull for sunset/sunrises) - needs testing
    - added switch for forcing nightlight value - #define PWM_FORCE_NIGHT_VALUE 1 -when 1% is too much
    - added constant #define WATER_TEMPERATURE_MIN for defining minimal water temperature used for coloring temperature on screensaver page
    [Nextion.ino, PWM.ino, aqualed.h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]
2017-02-03 default builtin pwms
2017-02-05 fixed bug when sunset was not starting
    [Nextion.ino, PWM.ino, aqualed.h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]
2017-02-05 added i2c_invert variable for i2c modules with inverted scale
    [PWM.ino, aqualed.h]
2017-02-06 fixed bug when pwmSaved was not updated during normal operation
    [PWM.ino, aqualed.h]
2017-02-06 sunset && sunrise times were off again ;) fixed
    [Aqualed.ino, PWM.ino, aqualed.h]
2017-02-07 bugfixes, new icons on Nextion screen
    [Nextion.ino, aqualed.h, nextion.h]
2017-02-09 fixed buttons on settings page
2017-03-01 added Nextion 4.3" file and pcb layout made by sq6kbr (nano-reef.pl forum)
    [nextion-28.stl, nextion_28_bezel.stl]
2017-03-08 - rewritten nextion functions - cleaner and more friendly code - channel names set from software - restore sunset/sunrise after crash or manual mode - disable/enable user mode (with star) - all harwa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
    [Aqualed.ino, Bluetooth.ino, EEPROM.ino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]
2017-05-28 fixed dst time fixed bug caused forced mode during sunset/sunrise to hang
    [Nextion.ino, PWM.ino, Time.ino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]
2017-05-28 fixed bug when dimming to nightlight during sunset turned off the lamp for one cycle
    [PWM.ino]
2017-11-26 added PCB prototype board Eagle Cad and Gerber files
    [AquaLEd-drivers.brd, AquaLEd-drivers.sch, AquaLed-logic.brd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]
2017-11-26 added schematics images
2017-12-05 added moonphase simulation, fixed many bugs, reduced code, sunset/sunrise value recovery after shutdown/forced user mode
    [Aqualed.ino, EEPROM.ino, Nextion.ino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]
2017-12-07 WARNING! EEPROM structure changed! DAY & PROG Values need to be re-set.
    - further code optimization (saved approx. 2kb)
    - code tidy-up for pwm data : settings and runtime data separated
    - added new screens: for saving data and critical error (lamp overheating
    and max wattage exceeding - set max values in config.h as needed)
    - pwm values now stored as: int (range 0-4048) for user prog and day
    values and raw data for nigh value (0-255). Night values dont map to pwm
    resolution, eg. when using build in arduino pins the values are 0-255
    out of 0-255, but when using I2C its 0-255 out of 0-4048. this gives
    more control over nightlight for those using i2c modules.
    - sunset/sunrise restore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
    [Aqualed.ino, EEPROM.ino, Nextion.ino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]
2017-12-17 temperature bugfix
2017-12-22 changed i2c library to https://github.com/NachtRaveVL/PCA9685-Arduino You can still use old Adafruit library, just uncomment //#define USE_ADAFRUIT_LIBRARY in config.h
2018-01-15 - Performance tweaks, bug fixes. - channel status - manualy switch relay on/off
    [Aqualed.ino, Nextion.ino, PWM.ino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]
2018-01-20 sunrise/sunset didn't stop in time
    [PWM.ino, aqualed.h]
2022-05-07 critical and performance fixes
    1. in nxTouch() there wasn't check on array lenght in read.serial()
    2. in pwm() there was not necessary calls to RTC.now() in each
    iteration. Reading RTC time now moved to separate funcion called every
    1s
    3. added Wire.setWireTimeout() for i2c devices
    4. other fixes and tweaks
    [Aqualed.ino, Nextion.ino, PWM.ino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]
2022-05-07 fixed first time read
    [Aqualed.ino, PWM.ino, Time.ino]
2022-05-14 Delete devs directory
    delete trash
    [AquaLEd-drivers.brd, AquaLEd-drivers.sch, AquaLed-logic.brd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]

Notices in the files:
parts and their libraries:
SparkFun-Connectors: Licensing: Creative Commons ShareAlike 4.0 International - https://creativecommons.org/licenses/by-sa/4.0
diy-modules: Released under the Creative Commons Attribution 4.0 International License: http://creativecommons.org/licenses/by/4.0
